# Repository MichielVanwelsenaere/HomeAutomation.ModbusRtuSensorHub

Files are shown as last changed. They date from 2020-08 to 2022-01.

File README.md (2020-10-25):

# Modbus RTU Sensor Hub



----------------------------

:rotating_light: This project is not yet in V1.0 state and is to be considered a work in progress. A release will be created when everything is working as expected.

----------------------------

This PCB with limited footprint is designed to provide a robust and versitale sensor hub using Modbus RTU over RS485. 

# PCB

## General
PCB measurements: ca 32mm x 30.5mm x 11mm

PCB Front                   | PCB Back
:--------------------------:|:-------------------------:
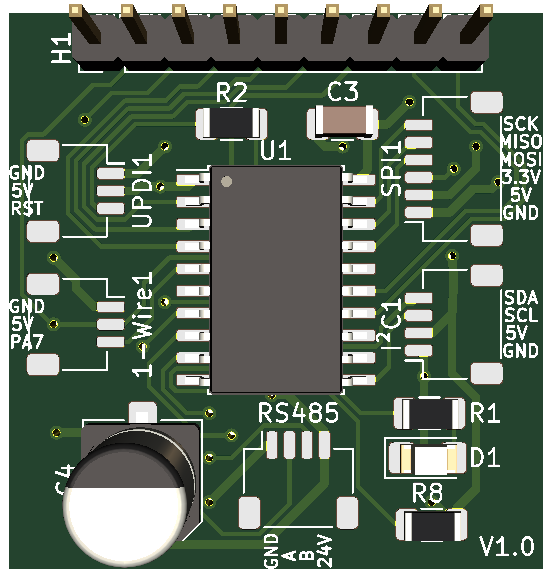
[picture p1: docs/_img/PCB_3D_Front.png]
PCB Front
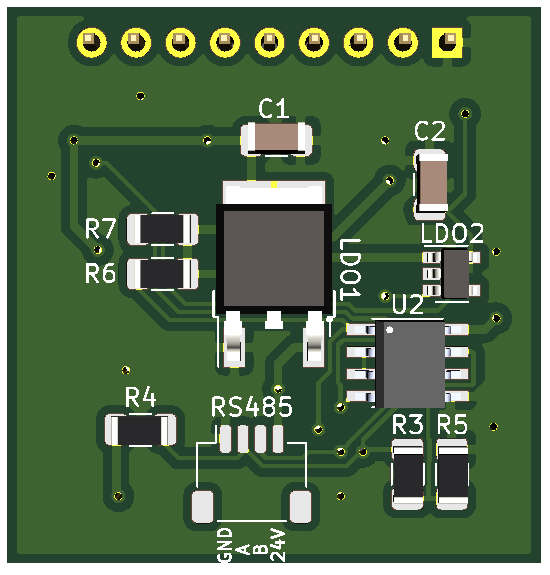
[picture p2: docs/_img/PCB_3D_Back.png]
PCB Back
  |  

## Microcontroller
The sensor hub leverages the very capable ATtiny3216 (arduino compatible!).

- 32Kb flash, 2k SRAM - that's the same as an ATmega328p!
- 17 available I/O pins
- 8 PWM pins (6 on TCA0, 2 on TCD0) with 8-bit resolution.
- Servo, Tone, Serial, SPI and Wire (I2C) support "just works"
- 2 Type B timers - so Servo and Tone can both be used simultaneously, or one or both can be taken over for input capture, periodic interrupt, or other functionality.
- DAC output (just do analogWrite() on the DAC pin - voltage is between 0V and the DAC reference voltage, which can be set with setDACReference() ).
- 11 analog inputs, referenced to Vcc, external reference, or one of the 5 built-in analog references.
Internal clock at up to 20MHz at 5v, up to 10MHz at 3.3v

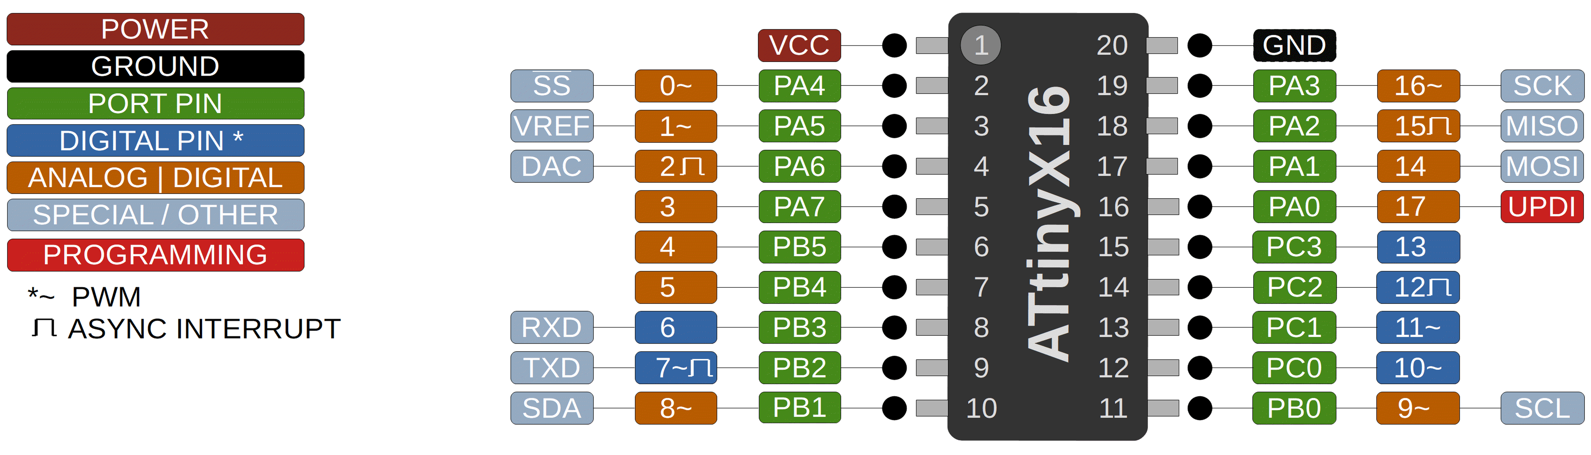
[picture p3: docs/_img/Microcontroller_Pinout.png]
Microcontroller Pinout


## Capabilities 

- wide range of allowed power supply voltage: 7-30V
- onboard convertor for 3.3V power supply (300mA max)
- onboard convertor for 5V power supply (1.5A max, board power consumption not included)
- two dedicated RS485 connector for leveraging Modbus RTU (bus in and out)
- dedicated 1-Wire connector
- dedicated UPDI connector for programming the board
- dedicated SPI connector
- dedicated I²C connector
- 2 remaining digital pins
- 4 remaining digital/analog pins

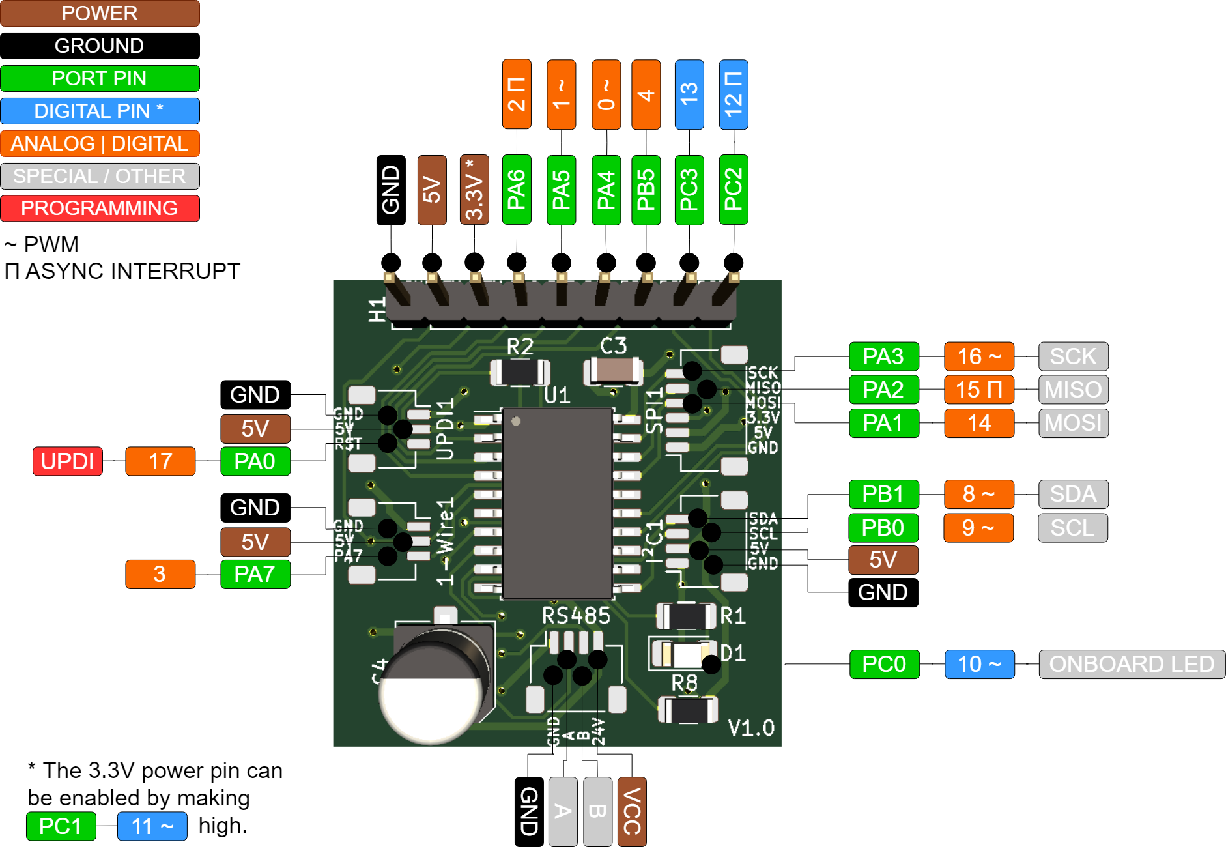
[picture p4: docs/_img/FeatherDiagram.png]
FeatherDiagram


# Getting started

- [Required Soldering Materials](./docs/Required-Soldering-Materials.md)
- [BOM (Bill Of Materials)](./docs/BOM.md)
- [Ordering the PCBs](./docs/Ordering-the-PCBs.md)
- [Soldering the PCBs](./docs/Soldering-the-PCBs.md)
- [Building an UPDI programmer](https://www.electronics-lab.com/project/getting-started-with-the-new-attiny-chips-programming-the-microchips-0-series-and-1-series-attiny-with-the-arduino-ide/)
- [Programming](./docs/Programming.md)

# Example projects

- [Blink](./docs/Example-projects/Blink/Blink.md)
- [BlinkAll](./docs/Example-projects/BlinkAll/BlinkAll.md)
- [ModbusRTU StaticValue](./docs/Example-projects/ModbusRTU_StaticValue/ModbusRTU_StaticValue.md)
- [ModbusRTU DS18B20](./docs/Example-projects/ModbusRTU_DS18B20/ModbusRTU_DS18B20.md)

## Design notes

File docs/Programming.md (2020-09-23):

## Programming

### Wire Diagram
Wire up the board to the UPDI programmer as shown below:

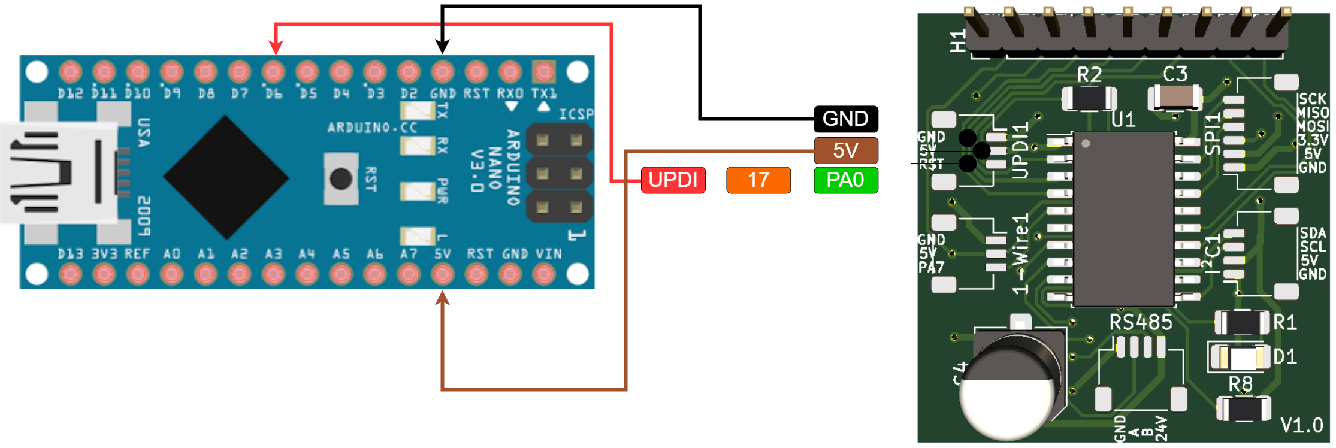
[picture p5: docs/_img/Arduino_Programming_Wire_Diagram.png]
Arduino IDE Tools Settings


When doing so, please disconnect any other powersupply to the board.

### Arduino IDE Preferences

1. (In the Arduino IDE) File > Preferences
1. Uncheck the checkbox next to "Show verbose output during: compilation"
1. Check the checkbox next to "Show verbose output during: upload
1. Click "OK"

This will avoid the error 'avrdude: jtagmkII_initialize(): Cannot locate "flash" and "boot" memories in description' during an upload. This is a spurious warning and can be safely ignored.

### Arduino IDE Tools Settings
Check if the following configuration is set before attempting an upload:

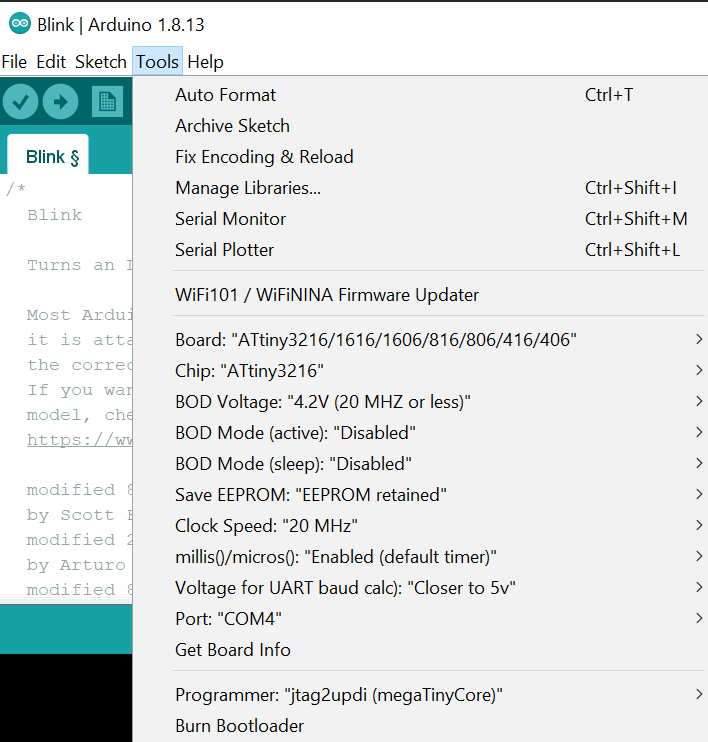
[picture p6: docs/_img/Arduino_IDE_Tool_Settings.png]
Arduino IDE Tools Settings


### Arduino IDE Upload using programmer
Use the following to upload the sketch to the board using the UPDI programmer:

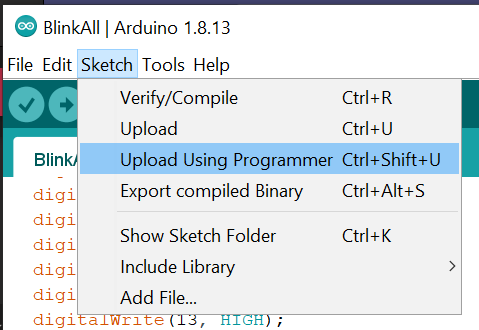
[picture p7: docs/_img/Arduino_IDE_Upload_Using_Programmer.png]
Arduino IDE Tools Settings


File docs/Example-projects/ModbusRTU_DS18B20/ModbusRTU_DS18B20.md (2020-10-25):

## ModbusRTU DS18B20

Exposes a DS18B20 temperature sensor value that can be read out leveraging Modbus RTU over RS485. 

## Libraries

- [Modbus-Master-Slave-for-Arduino by smarmengol](https://github.com/smarmengol/Modbus-Master-Slave-for-Arduino)
- [OneWire](https://github.com/PaulStoffregen/OneWire)
- [DallasTemperature](https://github.com/milesburton/Arduino-Temperature-Control-Library)

## Required hardware

- DS18B20 sensor ([counterfeit warning!](https://github.com/cpetrich/counterfeit_DS18B20)).

## Wire Diagram

## Sketch

[Link to Sketch](./ModbusRTU_DS18B20.ino)

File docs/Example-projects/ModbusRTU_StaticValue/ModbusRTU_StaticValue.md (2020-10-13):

## ModbusRTU_StaticValue

Exposes a static value that can be read out leveraging Modbus RTU over RS485. 

## Libraries

- [Modbus-Master-Slave-for-Arduino by smarmengol](https://github.com/smarmengol/Modbus-Master-Slave-for-Arduino)

## Required hardware

None.

## Wire Diagram

## Sketch

[Link to Sketch](./ModbusRTU_StaticValue.ino)

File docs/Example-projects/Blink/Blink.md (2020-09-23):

## Blink

Turns an LED on for one second, then off for one second, repeatedly.

## Required hardware

None, leverages the onboard LED.

## Sketch

[Link to Sketch](./Blink.ino)

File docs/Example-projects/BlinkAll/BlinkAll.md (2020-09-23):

## BlinkAll

Turns an all IO pins on for one second, then off for one second, repeatedly. Ideal for testing the board after soldering it.

## Required hardware

None.

## Sketch

[Link to Sketch](./BlinkAll.ino)

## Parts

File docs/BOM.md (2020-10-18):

## BOM

| Component | Form factor | Value | QTY/PCB | Link | Note |
|:---|:---|:---|:---|:---|:---|
| **LDO1** | TO-252-3 | / | 1 | [Mouser.be](https://www.mouser.be/ProductDetail/511-LD1086DT50TR) |
| **LDO2** | SOT-23-5 | / | 1 | [Mouser.be](https://www.mouser.be/ProductDetail/998-MIC5504-3.3YM5TR) | Can de dropped if not using 3.3V power supply
| **U1 (ATTINY3216)** | SOIC-20 | / | 1 | [Mouser.be](https://www.mouser.be/ProductDetail/579-ATTINY3216-SNR) |
| **U2 (MAX1487CSA)** | SOP-8 | / | 1 | [Mouser.be](https://www.mouser.be/ProductDetail/Maxim-Integrated/MAX1487CSA%2b?qs=1THa7WoU59GgTJYddUnO4w%3D%3D), [Aliexpress.com](https://www.aliexpress.com/item/32796877952.html) |
| **C1-3** | 1206 (3216) | 100uF | 3 | [Aliexpress.com](https://www.aliexpress.com/item/32966490820.html) | C2 can de dropped if not using 3.3V power supply
| **C4** | D6,3xL7,7mm SMD | 35V 100uF | 1 | [Aliexpress.com](https://www.aliexpress.com/item/33013972369.html) |
| **R1** | 1206 (3216) | 300Ohm | 1 | [Aliexpress.com](https://www.aliexpress.com/item/32847115923.html) |  Can de dropped if not using onboard LED (not advised however)
| **R2** | 1206 (3216) | 4.7kOhm | 1 | [Aliexpress.com](https://www.aliexpress.com/item/32847115923.html) |
| **R3** | 1206 (3216) | 120Ohm | 1 | [Aliexpress.com](https://www.aliexpress.com/item/32847115923.html) |
| **R4-8** | 1206 (3216) | 10kOhm | 5 | [Aliexpress.com](https://www.aliexpress.com/item/32847115923.html) |
| **D1 (led)** | 1206 (3216) | blue | 1 | [Aliexpress.com](https://www.aliexpress.com/item/32369344670.html) | Can de dropped if not using onboard LED (not advised however)
| **Headers** | 2.54mm pitch | / | 9 | [Aliexpress.com](https://www.aliexpress.com/item/32980406694.html) | Can be dropped if not using onboard headers
| **JST SH 1.0mm female connector** | SMD Horizontal 6 pin | / | 1 | [Aliexpress.com](https://www.aliexpress.com/item/4000125444790.html) |
| **JST SH 1.0mm female connector** | SMD Horizontal 4 pin | / | 3 | [Aliexpress.com](https://www.aliexpress.com/item/4000125444790.html) |
| **JST SH 1.0mm female connector** | SMD Horizontal 3 pin | / | 2 | [Aliexpress.com](https://www.aliexpress.com/item/4000125444790.html) |

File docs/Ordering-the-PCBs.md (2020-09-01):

## Ordering the PCBs
In this example [JLCPCB]() is used to order the PCBs.

1. Go to [JLCPCB]() and register if haven't already
1. Go to the 'Order Now' page
1. Upload the zip file found under [src](https://github.com/MichielVanwelsenaere/HomeAutomation.ModbusRtuSensorHub/tree/master/src)
1. Select the desired quantity of PCBs
1. Press 'Save To Cart' and finish your order

Below is an example including price of 30 PCBs:
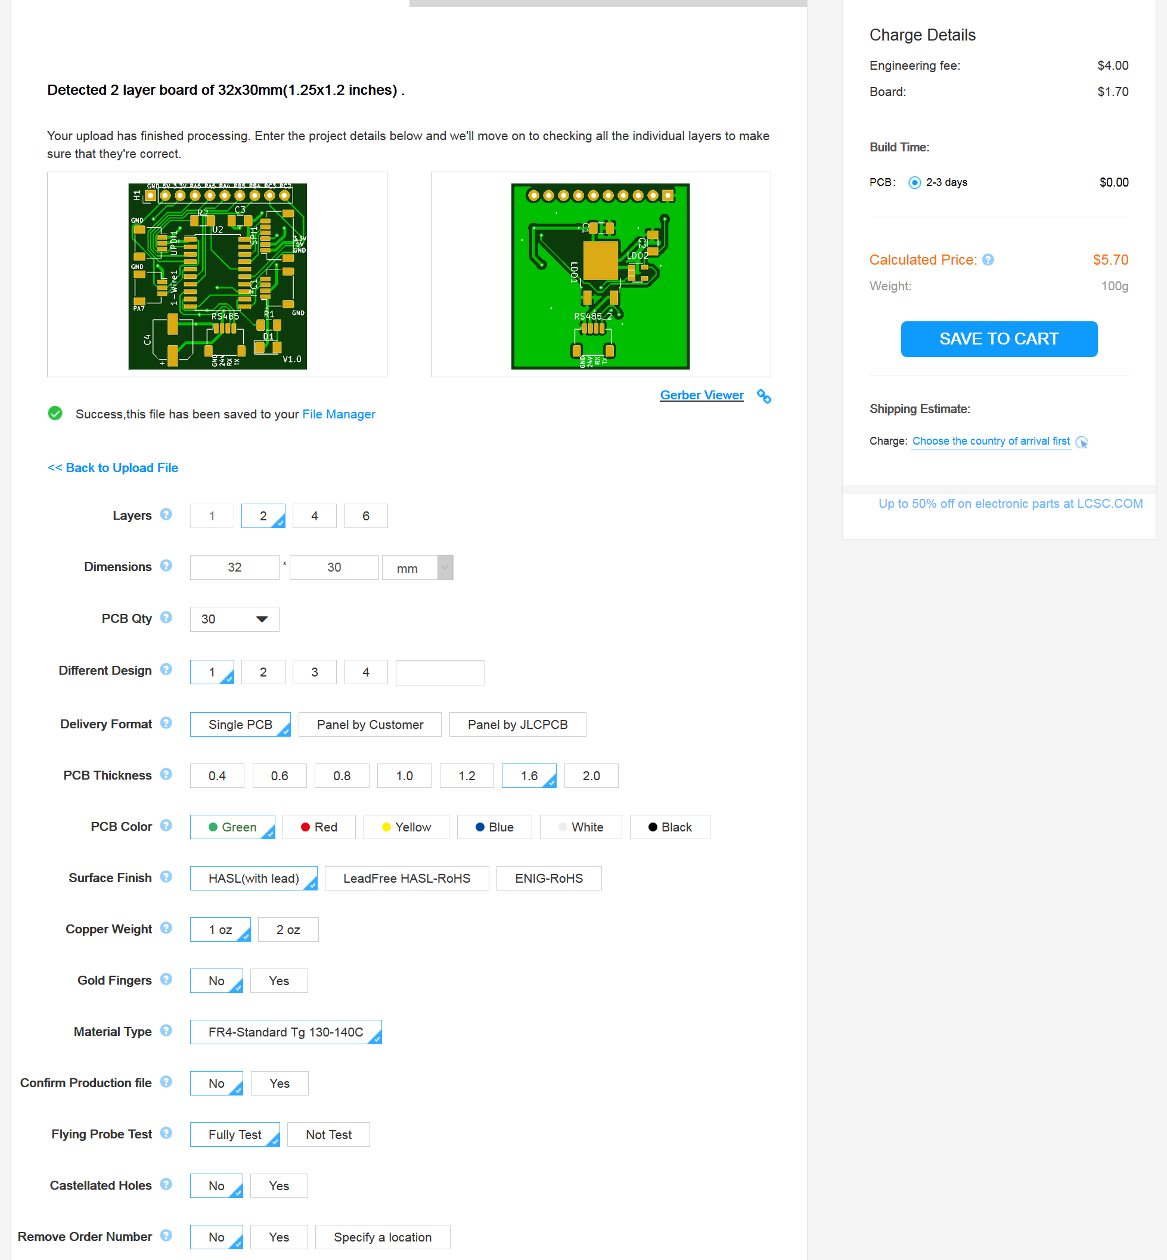
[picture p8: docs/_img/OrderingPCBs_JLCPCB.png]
JLCPCB order example


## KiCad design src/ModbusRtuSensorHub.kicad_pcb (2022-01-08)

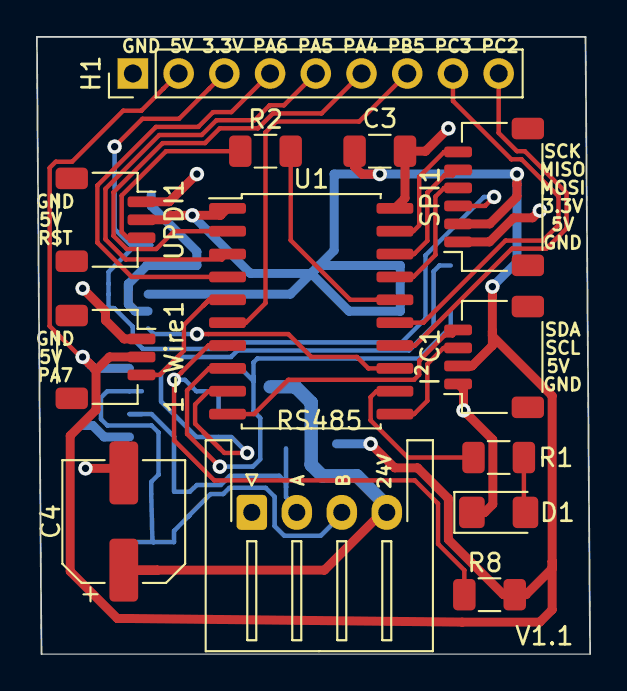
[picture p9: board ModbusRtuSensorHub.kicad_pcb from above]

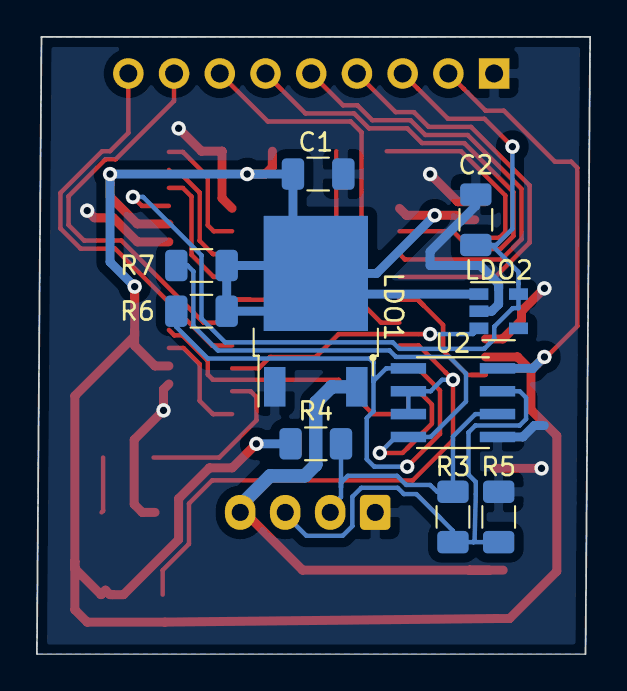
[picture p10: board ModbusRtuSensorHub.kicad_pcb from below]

Board: 2 copper layers, 30.7 x 34.3 mm, 23 parts (10 on the bottom side), 26 nets.

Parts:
1-Wire1: Conn_01x03; JST_SH_SM03B-SRSS-TB_1x03-1MP_P1.00mm_Horizontal
C1, C2, C3: 100u; C_1206_3216Metric
C4: 100u; CP_Elec_6.3x7.7
D1: LED; LED_1206_3216Metric_Pad1.42x1.75mm_HandSolder
H1: Conn_01x9; PinHeader_1x09_P2.54mm_Vertical
I²C1: Conn_01x04; JST_SH_SM04B-SRSS-TB_1x04-1MP_P1.00mm_Horizontal
LDO1: LD1086DT50TR; TO-252-2
LDO2: MIC5504-3.3YM5; SOT-23-5
R1: 300; R_1206_3216Metric
R2: 4.7k; R_1206_3216Metric
R3: 120; R_1206_3216Metric
R4, R5, R6, R7, R8: 10k; R_1206_3216Metric
RS485: Conn_01x04; JST_XH_S4B-XH-A-1_1x04_P2.50mm_Horizontal
SPI1: Conn_01x06; JST_SH_SM06B-SRSS-TB_1x06-1MP_P1.00mm_Horizontal
U1: ATtiny3216-S; SOIC-20W_7.5x12.8mm_P1.27mm
U2: MAX1487CSA+T; SOIC127P600X175-8N
UPDI1: Conn_01x03; JST_SH_SM03B-SRSS-TB_1x03-1MP_P1.00mm_Horizontal

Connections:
/3.3V: C2.1, H1.3, LDO2.5, SPI1.3
/5V: 1-Wire1.2, C1.1, C3.1, H1.2, I²C1.2, LDO1.2, LDO2.1, R4.1, R6.1, R7.1, R8.1, SPI1.2, U1.1, U2.8, UPDI1.2
/24V: C4.1, LDO1.3, RS485.4
/A: R3.1, R4.2, RS485.2, U2.6
/B: R3.2, R5.2, RS485.3, U2.7
/GND: 1-Wire1.1, C1.2, C2.2, C3.2, C4.2, D1.1, H1.1, I²C1.1, LDO1.1, LDO2.2, R5.1, RS485.1, SPI1.1, U1.20, U2.5, UPDI1.1
/MISO: SPI1.5, U1.18
/MOSI: SPI1.4, U1.17
/PA4: H1.6, U1.2
/PA5: H1.5, U1.3
/PA6: H1.4, U1.4
/PA7: 1-Wire1.3, U1.5
/PB4: R8.2, U1.7, U2.2, U2.3
/PB5: H1.7, U1.6
/PC2: H1.9, U1.14
/PC3: H1.8, U1.15
/RST: R2.1, U1.16
/RX: R6.2, U1.8, U2.1
/SCK: SPI1.6, U1.19
/SCL: I²C1.3, U1.11
/SDA: I²C1.4, U1.10
/TX: R7.2, U1.9, U2.4
unnamed: D1.2, R1.2
unnamed: LDO2.3, U1.13
unnamed: R1.1, U1.12
unnamed: R2.2, UPDI1.3

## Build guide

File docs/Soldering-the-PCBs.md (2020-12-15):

## Soldering the PCBs
Leverage the approach, tips & advice below to solder the board(s) together with the [BOM](./BOM).

### Soldering Order

On the front side of the board, solder the components in the following order:

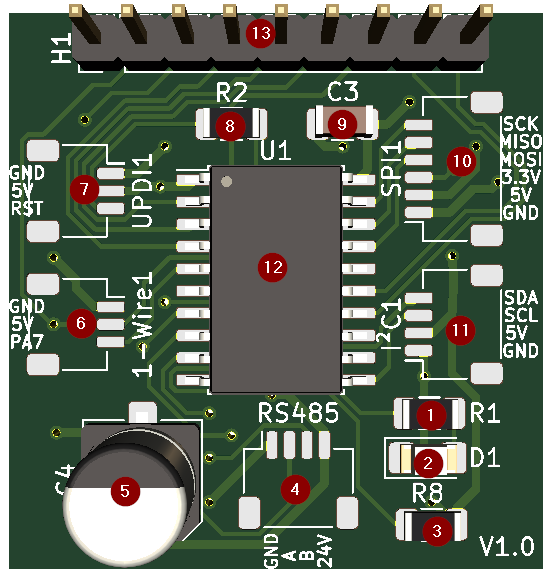
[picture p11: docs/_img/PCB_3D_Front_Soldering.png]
PCB Soldering Front


On the back side of the board, solder the components in the following order:

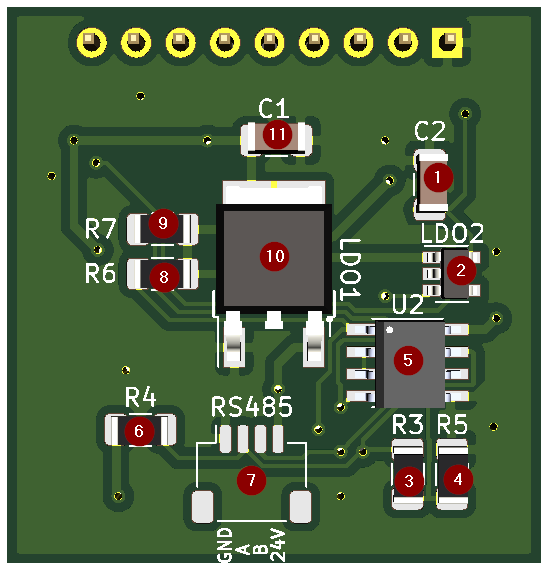
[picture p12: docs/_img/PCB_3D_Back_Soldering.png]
PCB Soldering Back


Note: this soldering order is a result of personal experience. Naturally you can solder the board in any order you see fit.

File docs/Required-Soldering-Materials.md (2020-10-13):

## Required Soldering Materials
Before starting make sure you have the required soldering materials listed below:

| Component |  Link | 
|:---|:---|
| **Soldering Iron** | 
| **Soldering Paste Flux** | [Aliexpress.com](https://www.aliexpress.com/item/32864986454.html)
| **Soldering Wire Flux** | [Aliexpress.com](https://www.aliexpress.com/item/32958719300.html)
| **Graphical Transistor/Resistance/Capacitance meter** (+9V battery) | [Aliexpress.com](https://www.aliexpress.com/item/32797743484.html)

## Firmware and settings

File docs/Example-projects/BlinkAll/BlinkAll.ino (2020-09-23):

// the setup function runs once when you press reset or power the board
void setup() {
  pinMode(10, OUTPUT);
  pinMode(9, OUTPUT);
  pinMode(8, OUTPUT);
  pinMode(14, OUTPUT);
  pinMode(15, OUTPUT);
  pinMode(16, OUTPUT);
  pinMode(12, OUTPUT);
  pinMode(13, OUTPUT);
  pinMode(5, OUTPUT);
  pinMode(4, OUTPUT);
  pinMode(0, OUTPUT);
  pinMode(1, OUTPUT);
  pinMode(2, OUTPUT);
  pinMode(3, OUTPUT);
  pinMode(11, OUTPUT);  
  pinMode(7, OUTPUT);
  pinMode(6, OUTPUT);

}

// the loop function runs over and over again forever
void loop() {
  digitalWrite(10, HIGH);   
  digitalWrite(9, HIGH);   
  digitalWrite(8, HIGH);   
  digitalWrite(14, HIGH);   
  digitalWrite(15, HIGH);   
  digitalWrite(16, HIGH);   
  digitalWrite(12, HIGH);   
  digitalWrite(13, HIGH);   
  digitalWrite(5, HIGH);   
  digitalWrite(4, HIGH);   
  digitalWrite(0, HIGH);   
  digitalWrite(1, HIGH);   
  digitalWrite(2, HIGH);   
  digitalWrite(3, HIGH);   
  digitalWrite(11, HIGH);  
  digitalWrite(7, HIGH);   
  digitalWrite(6, HIGH);    
  delay(1000);                       // wait for a second
  digitalWrite(10, LOW);    
  digitalWrite(9, LOW);   
  digitalWrite(8, LOW);   
  digitalWrite(14, LOW);   
  digitalWrite(15, LOW);   
  digitalWrite(16, LOW);   
  digitalWrite(12, LOW);   
  digitalWrite(13, LOW);   
  digitalWrite(5, LOW);   
  digitalWrite(4, LOW);   
  digitalWrite(0, LOW);   
  digitalWrite(1, LOW);   
  digitalWrite(2, LOW);   
  digitalWrite(3, LOW);   
  digitalWrite(11, LOW);   
  digitalWrite(7, LOW);   
  digitalWrite(6, LOW); 
  delay(1000);                       // wait for a second
}

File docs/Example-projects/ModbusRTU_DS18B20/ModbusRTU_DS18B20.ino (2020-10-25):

#include <ModbusRtu.h>
#include <OneWire.h>
#include <DallasTemperature.h>

#ifndef PIN_HWSERIAL0_XDIR 
#define PIN_HWSERIAL0_XDIR PIN_PB4
#endif

#define PIN_ONEWIRE PIN_PA7
#define SLAVEID 1 // ModBus Slave adres.
#define BAUDRATE 9600 // ModBus Slave baudrate.
 
// Modbus register data array (start register = 0)
union ModbusTemperature{  
  uint16_t au16data[2]; // 2 registers
  float temp; 
};

ModbusTemperature modbusTemperature;

OneWire oneWire(PIN_ONEWIRE);            
DallasTemperature sensors(&oneWire);   
 
/**
 *  Modbus object declaration
 *  u8id : node id = 0 for master, = 1..247 for slave
 *  u8serno : serial port (use 0 for Serial)
 *  u8txenpin : 0 for RS-232 and USB-FTDI or any pin number > 1 for RS-485
 */
Modbus slave(SLAVEID, Serial, PIN_HWSERIAL0_XDIR);
 
void setup() {
  pinMode(PIN_HWSERIAL0_XDIR,OUTPUT);
  Serial.begin(BAUDRATE, SERIAL_8N1);
  USART0.CTRLA|=USART_RS485_INT_gc;
  slave.start();
  sensors.begin();
}
 
void loop() {
  sensors.requestTemperatures(); 
  modbusTemperature.temp = sensors.getTempCByIndex(0);  
  slave.poll(modbusTemperature.au16data, 2);  
}

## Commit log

2020-03-28 Add files via upload
    Adding KiCad project to the branch
    [RS485-Modbus-Tiny-Sensor-Module.kicad_pcb, RS485-Modbus-Tiny-Sensor-Module.sch]
2020-03-28 Add files via upload
    Changed JST connection to smallest + fix connection to 3.3 V
    [RS485-Modbus-Tiny-Sensor-Module.kicad_pcb, RS485-Modbus-Tiny-Sensor-Module.sch]
2020-03-29 Add files via upload
    Added 24V LDO + cleaned layout + added autoreset
    [RS485-Modbus-Tiny-Sensor-Module.kicad_pcb, RS485-Modbus-Tiny-Sensor-Module.sch]
2020-03-30 Add files via upload
    Finished layout prototype + added extra JST
    [RS485-Modbus-Tiny-Sensor-Module.kicad_pcb, RS485-Modbus-Tiny-Sensor-Module.sch]
2020-04-01 Add files via upload
    Added BOM + .zip file that contains files for production of PCB
    [BOM.xlsx, RS485-Modbus-Tiny-Sensor-Module.kicad_pcb, RS485-Modbus-Tiny-Sensor-Module.sch]
2020-04-02 updating BOM with aliExpress links
    [BOM.xlsx]
2020-04-07 Add files via upload
    Checked BOM
    [BOM.xlsx]
2020-05-14 Add files via upload
    PCB V1.0
    [RS485-Modbus-Tiny-Sensor-Module.kicad_pcb, RS485-Modbus-Tiny-Sensor-Module.sch]
2020-08-20 reshaping project
    [BOM.xlsx, RS485-Modbus-Tiny-Sensor-Module.kicad_pcb, RS485-Modbus-Tiny-Sensor-Module.sch]
2020-08-20 still reshaping project
    [ModbusRtuSensorHub-B_Cu.gbr, ModbusRtuSensorHub-B_Mask.gbr, ModbusRtuSensorHub-B_Paste.gbr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]
2020-08-20 adding pcb images
2020-08-28 staging work, bom wip
2020-09-01 completing BOM
    [BOM.xlsx]
2020-09-01 updating required soldering materials
2020-09-01 working with zip for output and adding content on ordering the pcb docs page
    [ModbusRtuSensorHub-B_Cu.gbr, ModbusRtuSensorHub-B_Mask.gbr, ModbusRtuSensorHub-B_Paste.gbr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]
2020-09-02 completing required soldering materials
2020-09-21 updating BOM
2020-09-24 building all samples in PR workflow, wip
2020-10-18 updated pcb with onboard transciever
    [ModbusRtuSensorHub.kicad_pcb, ModbusRtuSensorHub.sch]
2020-10-18 updating PCB images
2020-10-18 updated BOM to new PCB
2020-10-25 working on arduino samples
2020-12-15 updating docs on soldering order
2022-01-08 latest version
    [ModbusRtuSensorHub.kicad_pcb, ModbusRtuSensorHub.sch]
